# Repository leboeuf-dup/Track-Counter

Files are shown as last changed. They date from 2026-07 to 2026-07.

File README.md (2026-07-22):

# Track Counter

An automated, low-power Track Counter that detects and records visitor traffic on walking and mountain-bike trails, removing the need for manual counts. Built as a proof-of-concept for organizations such as the Department of Conservation (DOC), the device uses an infrared (IR) sensor to detect passing visitors, stores the count locally on an Arduino, outputs a trigger pulse for optional external devices (e.g. a camera), and displays the accumulated count on an LCD at the press of a button.

Created: March 2025\
GitHub upload: Jul 2026

## Contributors

- Liam du Plessis
- Mark Watkins
- Samuel Holmes

## Breadboard prototype & Schematics

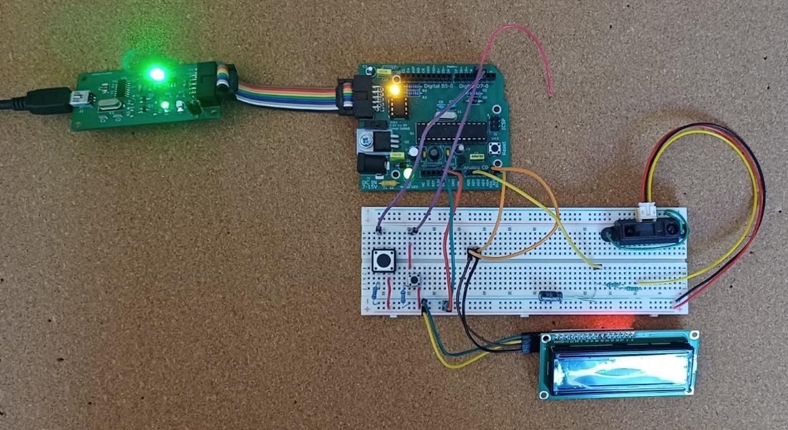
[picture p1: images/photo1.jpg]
Prototype


## Design Overview

The Track Counter meets the following design requirements:

- Uses a Sharp IR distance sensor to detect visitors on the track
- Stores the detection count locally, with no external cable or internet connection required
- Outputs a rectangular "trigger" pulse (50–100 ms, 4.5–5.2 V) with each detection
- Displays the count on an LCD at the press of a button
- Allows the count to be reset at the press of a separate button
- Detects visitors within a range of 40 cm (adjustable in software)
- Runs from a 5 V DC, 10,000 mAh power supply

## Hardware Description

| Building Block | Description |
|---|---|
| Arduino UNO R3 | Executes the program, stores the detection count, and communicates with all other components |
| Sharp IR Sensor (GP2Y0A21YK) | Converts a measured distance into a corresponding voltage signal |
| Low-Pass Filter | Passive RC filter (1 µF capacitor, 1.59 kΩ resistor, ~100 Hz cutoff) that removes high-frequency noise from the sensor signal before it reaches the Arduino |
| LCD Display Module (16×2, I2C) | Displays the current count to the surveyor |
| Tact Switches | Two buttons — a larger one to activate the display, and a smaller, less accessible one to reset the count — each using a 10 kΩ pull-down resistor for a clearly defined signal |

**Schematic**

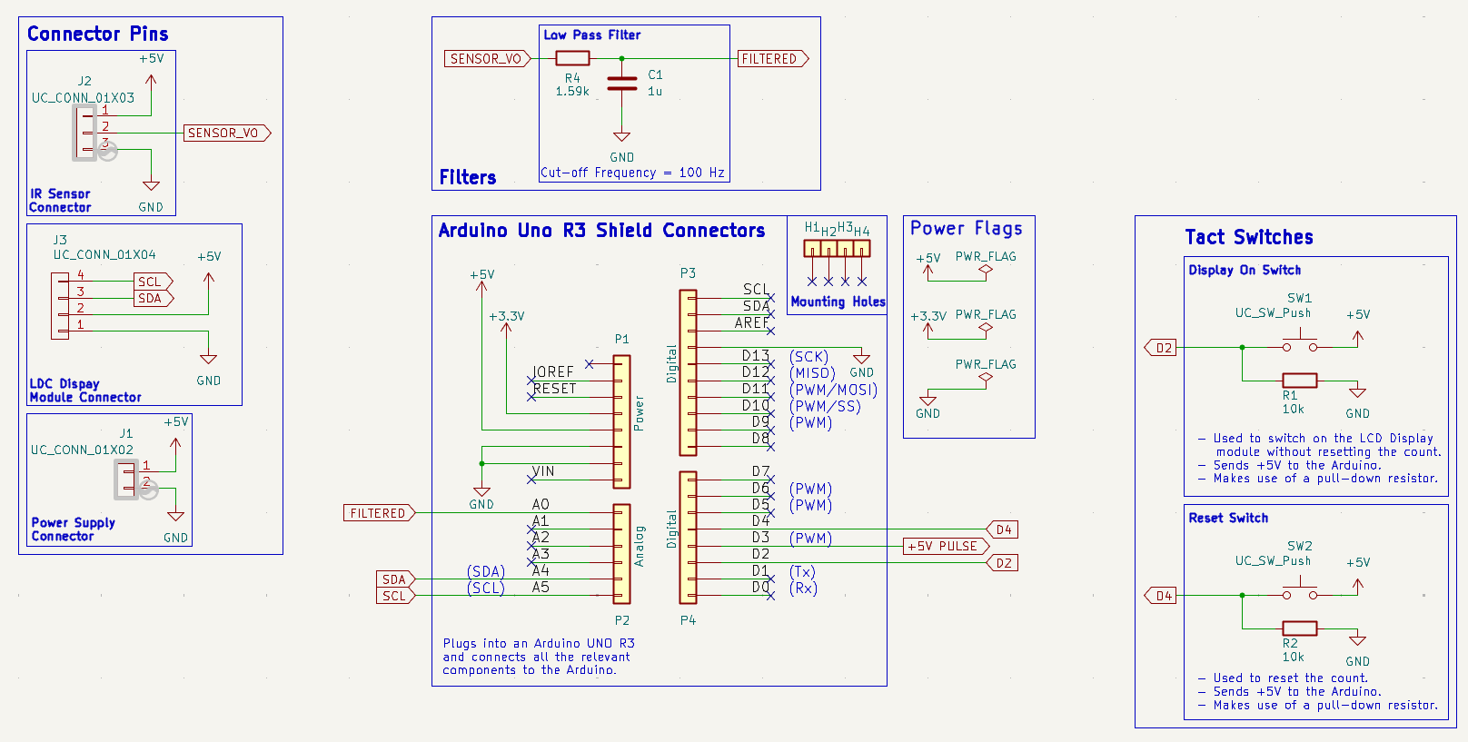
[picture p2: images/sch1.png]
KiCAD Schematic


**Arduino pin mapping:**

| Pin | Signal Type | Linked Component |
|---|---|---|
| A0 | Analog Input | IR sensor (via low-pass filter) |
| A4 / SDA | Analog | LCD module |
| A5 / SCL | Analog | LCD module |
| D2 | Digital Input | Display switch |
| D3 | Digital Output | Trigger signal |
| D4 | Digital Input | Reset switch |

A low-pass filter (rather than a Schmitt trigger) was chosen to clean up the IR sensor signal, as it is a cheap, compact, passive solution that avoids the extra power draw of an op-amp. Schematics and prototype photos are included in the full project report.

**Low-Pass Filter**

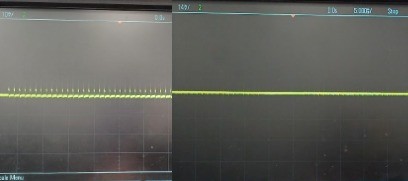
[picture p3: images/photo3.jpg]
Comparison Image
\
Before VS After signal

## Software Description

The Arduino is programmed via the Arduino IDE and runs a simple state-driven main loop:

1. On startup, the program initializes a `count` variable (set to 0) and a `tickOver` locking variable (set to locked).
2. Each loop iteration, the IR sensor voltage is read and passed through a low-pass filter.
3. When the sensor voltage crosses below the `CROSS_OVER_VOLTAGE` threshold, an object is considered "detected" and the counter unlocks.
4. When the voltage crosses back above the threshold (object leaving range), the `count` is incremented once, a 5 V trigger pulse is output, and the counter re-locks — preventing a single visitor from being counted multiple times while in range.
5. On every loop iteration, the count is written to the LCD (regardless of lock state), and the display/reset buttons are checked so they remain responsive at all times.
6. Pressing the display button turns the LCD on; releasing it turns the LCD off (a pull-down resistor prevents floating-voltage flicker).
7. Pressing the reset button clears the LCD and sets `count` back to 0, without resetting the entire Arduino program.

The LCD is driven using [Bill Perry's hd44780 library](https://github.com/duinoWitchery/hd44780), communicating over I2C (SDA/SCL).

## Bill of Materials

Total hardware cost: **$22.84 NZD** (well within the $40 budget constraint)

| Component | Quantity | Unit Cost ($) | Total Cost ($) |
|---|---|---|---|
| LCD Module | 1 | 6.00 | 6.00 |
| IR Distance Sensor | 1 | 6.80 | 6.80 |
| Solid Core Wire (per metre) | 0.05 m | 0.70 | 0.04 |
| Dupont Cables (M–M) | 7 | 0.00 | 0.00 |
| Dupont Cables (M–F) | 4 | 0.00 | 0.00 |
| Momentary Tact Switch (6 mm) | 1 | 0.25 | 0.25 |
| Momentary Tact Switch (12 mm) | 1 | 0.65 | 0.65 |
| Electrolytic Capacitor (1 µF) | 1 | 0.10 | 0.10 |
| Resistor | 4 | 0.00 | 0.00 |
| Arduino UNO | 1 | 9.00 | 9.00 |
| **Total** | | | **22.84** |

*Component pricing based on the UC Components Store catalogue.*

## Known Limitations

- Battery life is estimated at **5.95 days** under continuous sensor operation with a 10,000 mAh supply — short of the 10-day target. Limiting sensor activity to daylight hours (~12 hrs/day) improves this to ~7.72 days; further options include a FET-controlled sensor power switch for scheduled sensing windows.
- Groups of visitors passing closely together may be counted as a single detection event, due to the locking mechanism used to prevent multi-counting.

## Early Version PCB

This project followed introdutory labs in which initial versions of the step counter was made. This version includes a PCB layout shown below.

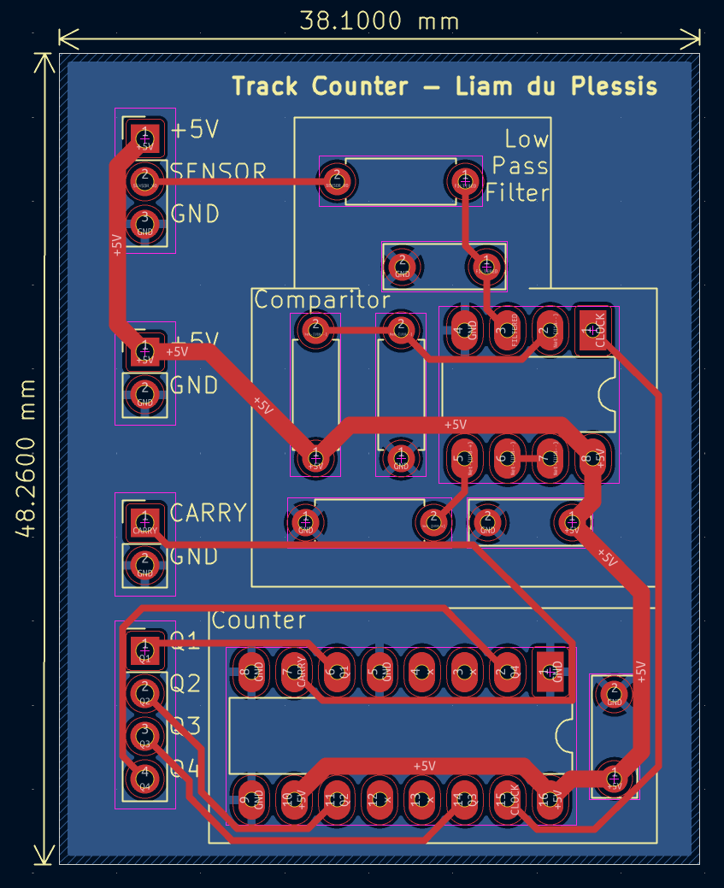
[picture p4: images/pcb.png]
PCB layout
\
PCB Layout (Made by Liam du Plessis)

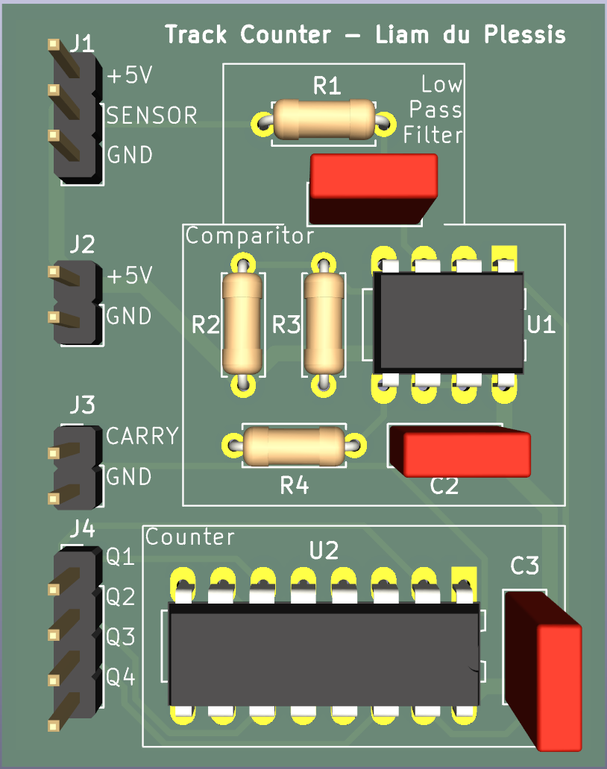
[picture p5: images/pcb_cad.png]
PCB CAD Model
\
PCB CAD Model

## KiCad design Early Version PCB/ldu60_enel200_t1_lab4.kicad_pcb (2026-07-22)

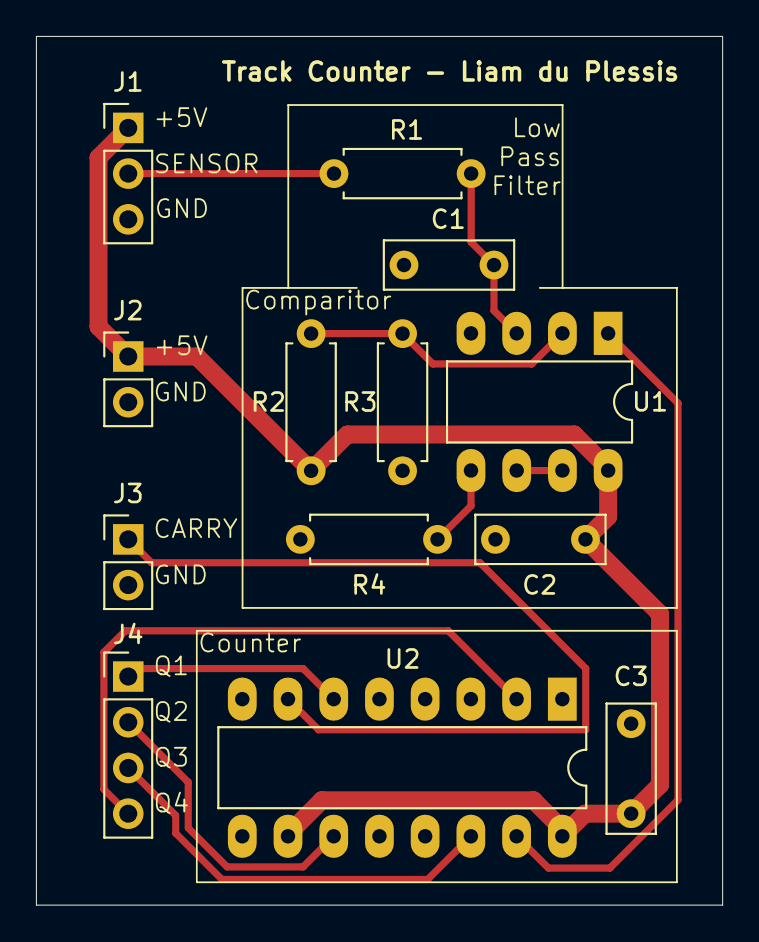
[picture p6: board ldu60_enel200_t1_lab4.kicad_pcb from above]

Board: 2 copper layers, 38.1 x 48.3 mm, 13 parts (0 on the bottom side), 13 nets.

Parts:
C1: 1u; C_Rect_L7.0mm_W2.5mm_P5.00mm
C2, C3: 0.1u; C_Rect_L7.0mm_W2.5mm_P5.00mm
J1: UC_CONN_01X03; PinHeader_1x03_P2.54mm_Vertical
J2, J3: UC_CONN_01X02; PinHeader_1x02_P2.54mm_Vertical
J4: UC_CONN_01X04; PinHeader_1x04_P2.54mm_Vertical
R1: 1.59k; R_Axial_DIN0207_L6.3mm_D2.5mm_P7.62mm_Horizontal
R2: 567k; R_Axial_DIN0207_L6.3mm_D2.5mm_P7.62mm_Horizontal
R3, R4: 100k; R_Axial_DIN0207_L6.3mm_D2.5mm_P7.62mm_Horizontal
U1: UC_LM358; DIP-8_W7.62mm_LongPads
U2: UC_CD4510B; DIP-16_W7.62mm_LongPads

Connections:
+5V: C2.1, C3.1, J1.1, J2.1, R2.1, U1.8 (V+), U2.10 (U/D), U2.16 (VDD)
/SENSOR_VO: J1.2, R1.2
CARRY: J3.1, U2.7 (~COUT)
CLOCK: U1.1, U2.15 (CLK)
FILTERED: C1.1, R1.1, U1.3 (+)
GND: C1.2, C2.2, C3.2, J1.3, J2.2, J3.2, R3.1, R4.1, U1.4 (V-), U2.1 (PEN), U2.5 (~CIN), U2.8 (VSS), U2.9 (RST)
unnamed: R2.2, R3.2, U1.2 (-)
unnamed: R4.2, U1.5 (+)
unnamed: U1.6 (-), U1.7
Q1: J4.1, U2.6 (Q1)
Q2: J4.2, U2.11 (Q2)
Q3: J4.3, U2.14 (Q3)
Q4: J4.4, U2.2 (Q4)

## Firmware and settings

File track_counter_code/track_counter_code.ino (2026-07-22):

/*
  Program to receive voltage signals from a Sharp IR sensor,
  increment a counter and display the count on an LCD display
  module.

  Use Bill Perry's HD44780 library.
  Install through the Arduino IDE library manager:
  (Tools > Manage libraries, then search for "Extensible hd44780")
  See https://github.com/duinoWitchery/hd44780 for documentation and other examples
*/

#include <Wire.h>
#include <hd44780.h>
#include <hd44780ioClass/hd44780_I2Cexp.h> // Use the I2C interface

// *** Configuration for I/O pins ***
const int ioPinLed = 7;      // The D7 pin is connected to the LED
const int ioPinSensor = A0;  // Using A0 as the sensor input
const int ioPinDisplay = 2;  // Using D2 to activate the display
const int ioPinPulse = 3;    // Using D3 to output a pulse
const int ioPinReset = 4;    // Using D4 to receive a reset signal

// *** Global Constants relating to the LCD ***
hd44780_I2Cexp lcd;          // Autoconfigure the LCD
const int LCD_COLS = 16;
const int LCD_ROWS = 2;
const int PULSE_DELAY = 50;

// *** Other configuration constants ***
const int UPDATE_INTERVAL_MSEC = 100;   // Defines between sensor readings (100 ms)
const float CROSS_OVER_VOLT = 0.75;     // Sensor voltage == 40cm reading
const float VOLTAGE_CONV_RATIO = (1023 / 5);   // Ratio to convert sensor signal to volts
const uint32_t BAUD_RATE = 115200;      // High "baud rate" to minimize the time taken to send serial outputs

unsigned long lastUpdateTime = -1;

// *** Global variables ***
int count = 0;
int tickOver = 0; // Tick to prevent over counting.

void setup() {
  // Assign pins
  pinMode(ioPinLed, OUTPUT);
  pinMode(ioPinDisplay, INPUT);
  pinMode(ioPinPulse, OUTPUT);
  Serial.begin(BAUD_RATE);

  // Set up LCD
  int status = lcd.begin(LCD_COLS, LCD_ROWS);
  if (status != 0) {
    hd44780::fatalError(status);  // Hangs the program
  }
  lcd.clear();
  lcd.print("COUNT:");
  lcd.setCursor(0, 1);
  lcd.print(count);
}

void loop() {
  // Turn the LED on during each sample/output to give
  // a visual indication of how quickly the sampling is happening.
  digitalWrite(ioPinLed, HIGH);
  digitalWrite(ioPinLed, LOW);
  delay(UPDATE_INTERVAL_MSEC);

  // Read and return sensor values and convert to a voltage.
  float adcValue = analogRead(ioPinSensor);
  float sensorVoltage = adcValue / (VOLTAGE_CONV_RATIO);
 
  // Process voltage and increase count accordingly.
  countUp(sensorVoltage);
  printVals(sensorVoltage, count);

  // Print the current counter in the corresponding column
  lcd.setCursor(0, 1);
  lcd.print(count);
 
  // Switches display on and off via a switch
  int switchDisplay = digitalRead(ioPinDisplay);
  manageDisplay(switchDisplay);

  int switchReset = digitalRead(ioPinReset);
  resetDisplay(switchReset);
}

void countUp(float voltage) {
  if (tickOver == 0) {
      if (voltage <= CROSS_OVER_VOLT) {
        tickOver = 1;
      }
    }
    else {
      if (voltage > CROSS_OVER_VOLT) {
        count += 1;
        digitalWrite(ioPinPulse, HIGH);
        delay(PULSE_DELAY);
        digitalWrite(ioPinPulse, LOW);
        tickOver = 0;
      }
    }
}

void printVals(float voltage, int count) {
  Serial.print("Voltage:"); // Label the data in the serial plotter
  Serial.println(voltage);
  Serial.print("count:"); // Label the data in the serial plotter
  Serial.println(count);
  }

void manageDisplay(int digiVal) {   // Manages the display light using a digital value
  if (digiVal == 1) {
    lcd.on();
    }
    else {
      lcd.off();
    }
}

void resetDisplay(int digiVal) {   // Resets count
  if (digiVal == 1) {
    count = 0;
    lcd.clear();
    lcd.print("COUNT:");
  }
}

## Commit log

2026-07-22 Paste some of the work done
    [ldu60_enel200_t1_lab4.kicad_pcb, ldu60_enel200_t1_lab4.kicad_sch]
2026-07-22 Rest of the work done
    [UCArduinoShieldTemplate.kicad_pcb, UCArduinoShieldTemplate.kicad_sch, ldu60_enel200_t1_track_counter.kicad_pcb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]
